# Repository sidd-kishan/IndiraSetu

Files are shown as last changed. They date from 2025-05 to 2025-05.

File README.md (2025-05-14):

# IndraSetu
## pi pico <-> ft232h
#### GPIO2 -> CLKOUT
#### GPIO3 -> RXF#
#### GPIO4 -> TXE#

#### GPIO5 -> OE#
#### GPIO6 -> RD#
#### GPIO7 -> WR#

#### GPIO8 -> BIT0

#### 3v3  + 3.3v -> ili9341 VCC -> LED ( this is for the lcd back light will be only be labled as led ) needs 3v3 volts from both the chips to balance current draw.

## pi pico -> ili9341 

Sending data which is emiting from pc through ft232h into pi pico with the help of PIO state machine

(PC + FT232H) -> Pi Pico

https://ftdichip.com/wp-content/uploads/2023/09/DS_FT232H.pdf page9


https://ftdichip.com/wp-content/uploads/2020/08/TN_167_FIFO_Basics.pdf page15


Refrences:-
[AN130](https://ftdichip.com/wp-content/uploads/2020/08/AN_130_FT2232H_Used_In_FT245-Synchronous-FIFO-Mode.pdf)
[AN135](https://www.ftdichip.com/Documents/AppNotes/AN_135_MPSSE_Basics.pdf)
[AN165](https://www.ftdichip.com/Documents/AppNotes/AN_165_Establishing_Synchronous_245_FIFO_Communications_using_a_Morph-IC-II.pdf)
[AN167](https://ftdichip.com/wp-content/uploads/2020/08/TN_167_FIFO_Basics.pdf)
[AN124](https://www.ftdichip.cn/Support/Documents/AppNotes/oldAN_124_User_Guide_For_FT_PROG.pdf)



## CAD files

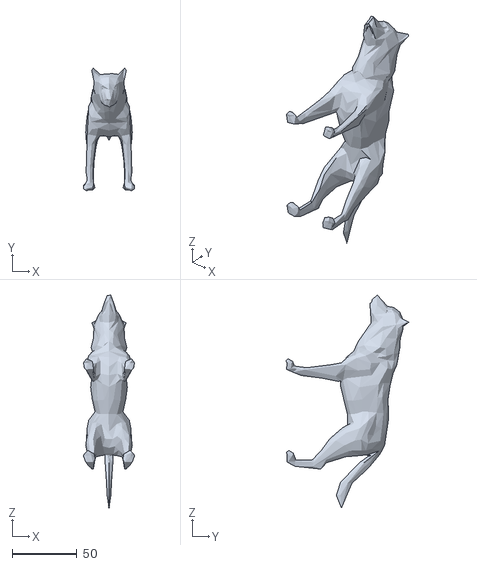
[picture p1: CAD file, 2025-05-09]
WOLF.obj
39.3 x 94.6 x 164.0

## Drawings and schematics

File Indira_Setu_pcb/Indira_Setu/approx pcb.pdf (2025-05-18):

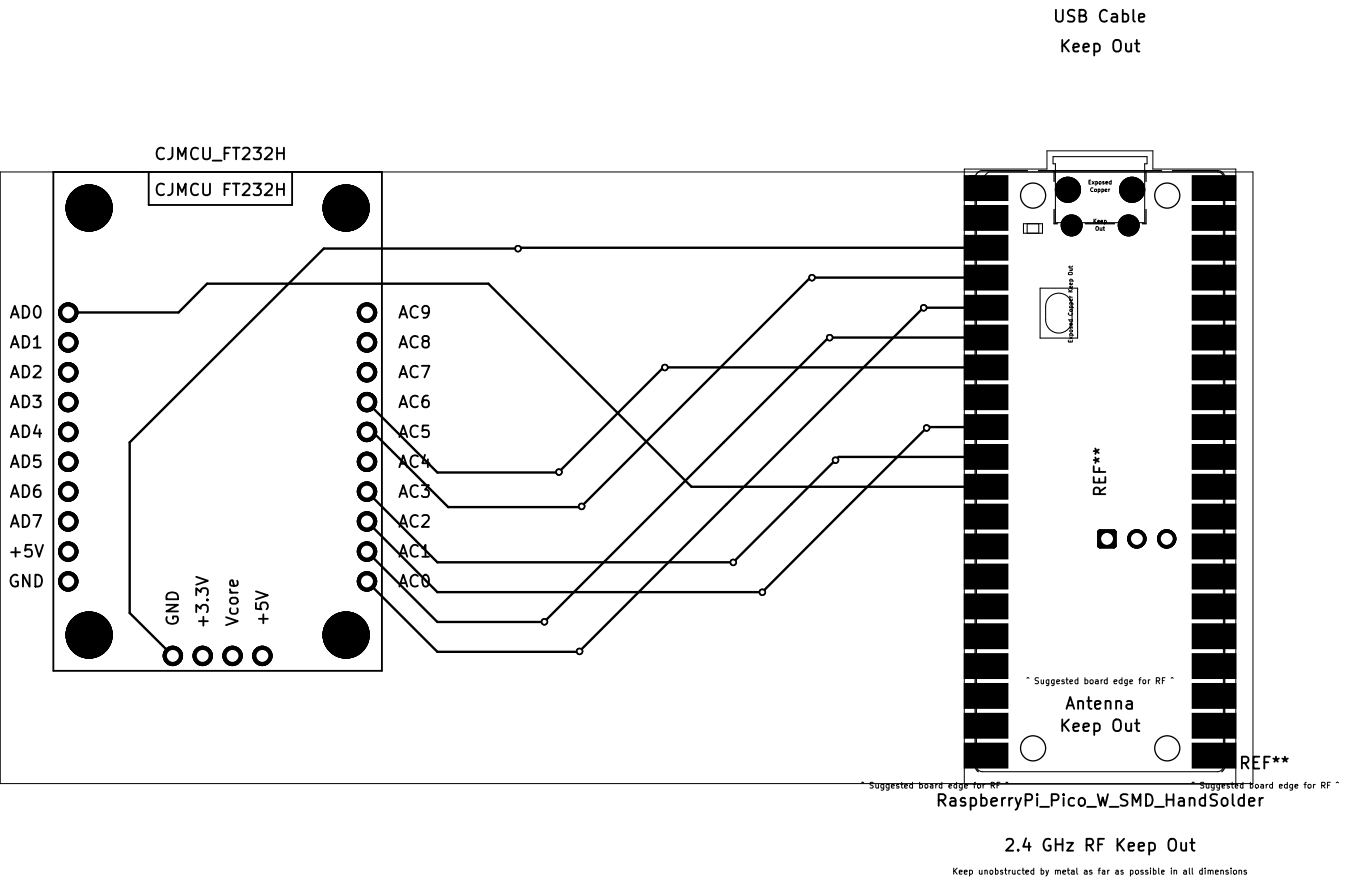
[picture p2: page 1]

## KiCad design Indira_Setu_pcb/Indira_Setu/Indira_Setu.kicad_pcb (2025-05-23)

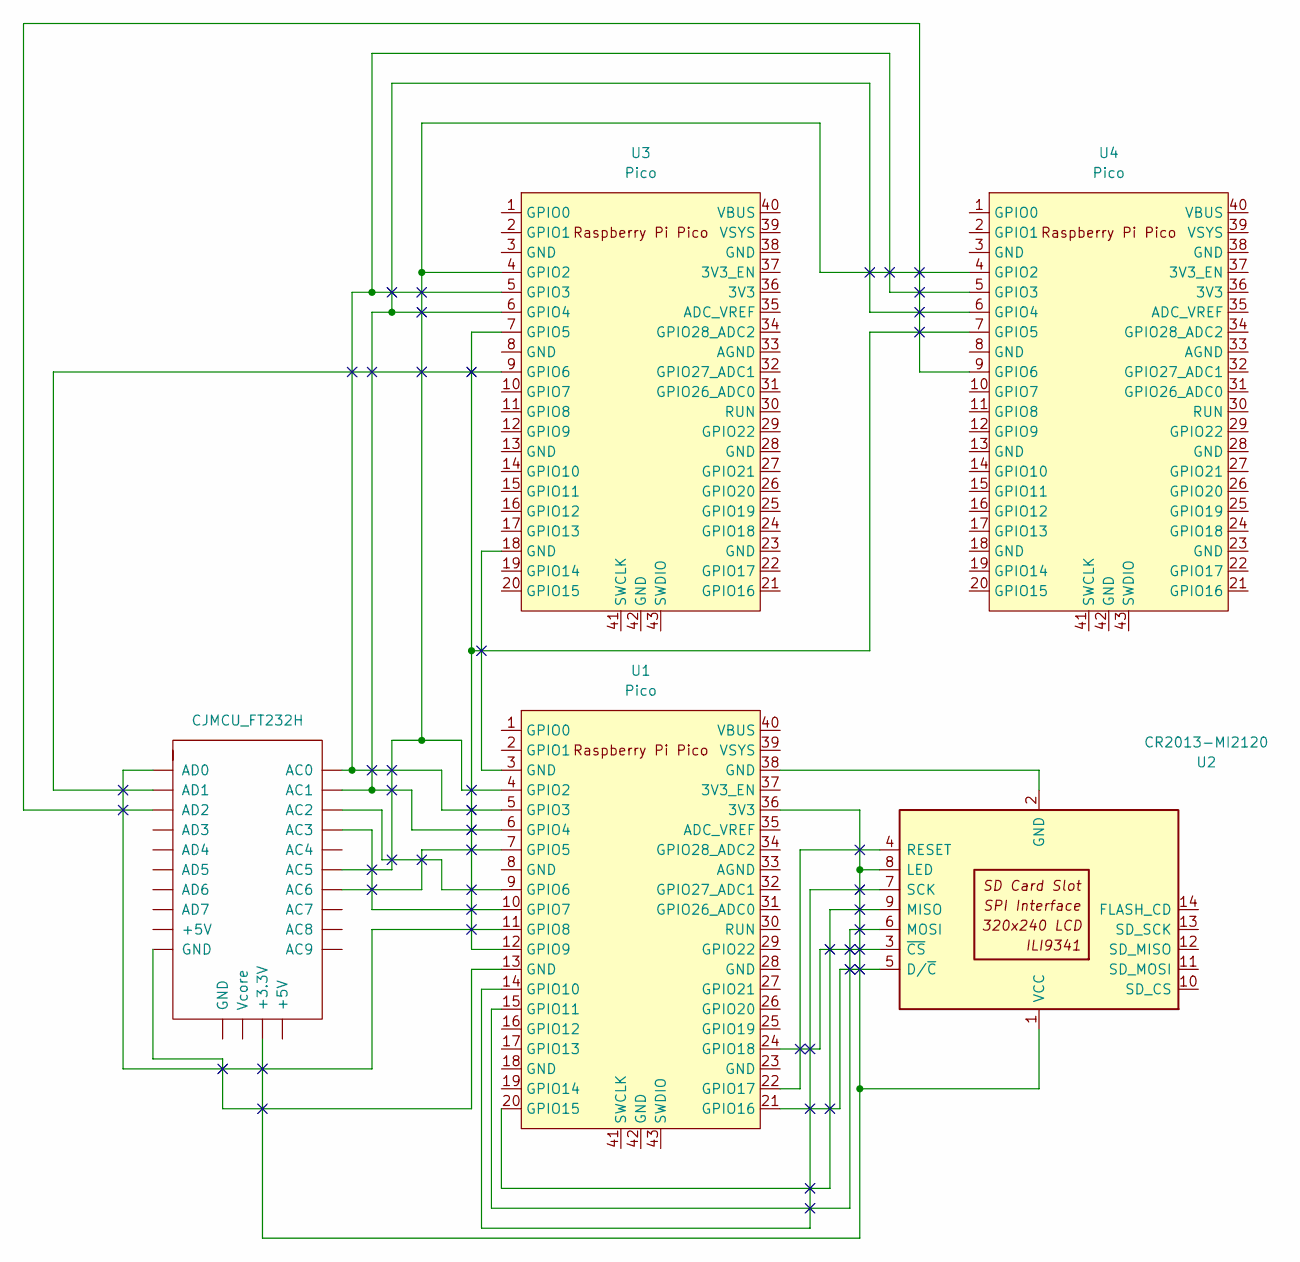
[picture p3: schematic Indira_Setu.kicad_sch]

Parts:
CJMCU_FT1: CJMCU_FT232H
U1, U3, U4: Pico; RPi_Pico_SMD_TH
U2: CR2013-MI2120

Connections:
unnamed: CJMCU_FT1.GND1 (GND), U1.13 (GND)
unnamed: CJMCU_FT1.+3.3V, U1.36 (3V3), U2.1 (VCC), U2.8 (LED)
unnamed: U1.3 (GND), U3.18 (GND)
unnamed: CJMCU_FT1.AC5, U1.4 (GPIO2), U3.4 (GPIO2), U4.4 (GPIO2)
unnamed: CJMCU_FT1.AC0, U1.5 (GPIO3), U3.5 (GPIO3), U4.5 (GPIO3)
unnamed: CJMCU_FT1.AC1, U1.6 (GPIO4), U3.6 (GPIO4), U4.6 (GPIO4)
unnamed: CJMCU_FT1.AC6, U1.7 (GPIO5)
unnamed: CJMCU_FT1.AC2, U1.9 (GPIO6)
unnamed: CJMCU_FT1.AC3, U1.10 (GPIO7)
unnamed: CJMCU_FT1.AD0, U1.11 (GPIO8)
unnamed: U1.12 (GPIO9), U3.7 (GPIO5), U4.7 (GPIO5)
unnamed: U1.14 (GPIO10), U2.7 (SCK)
unnamed: U1.15 (GPIO11), U2.6 (MOSI)
unnamed: U1.20 (GPIO15), U2.9 (MISO)
unnamed: U1.21 (GPIO16), U2.5 (D/~C)
unnamed: U1.22 (GPIO17), U2.4 (RESET)
unnamed: U1.24 (GPIO18), U2.3 (~CS)
unnamed: U1.38 (GND), U2.2 (GND)
unnamed: CJMCU_FT1.AD1, U3.9 (GPIO6)
unnamed: CJMCU_FT1.AD2, U4.9 (GPIO6)

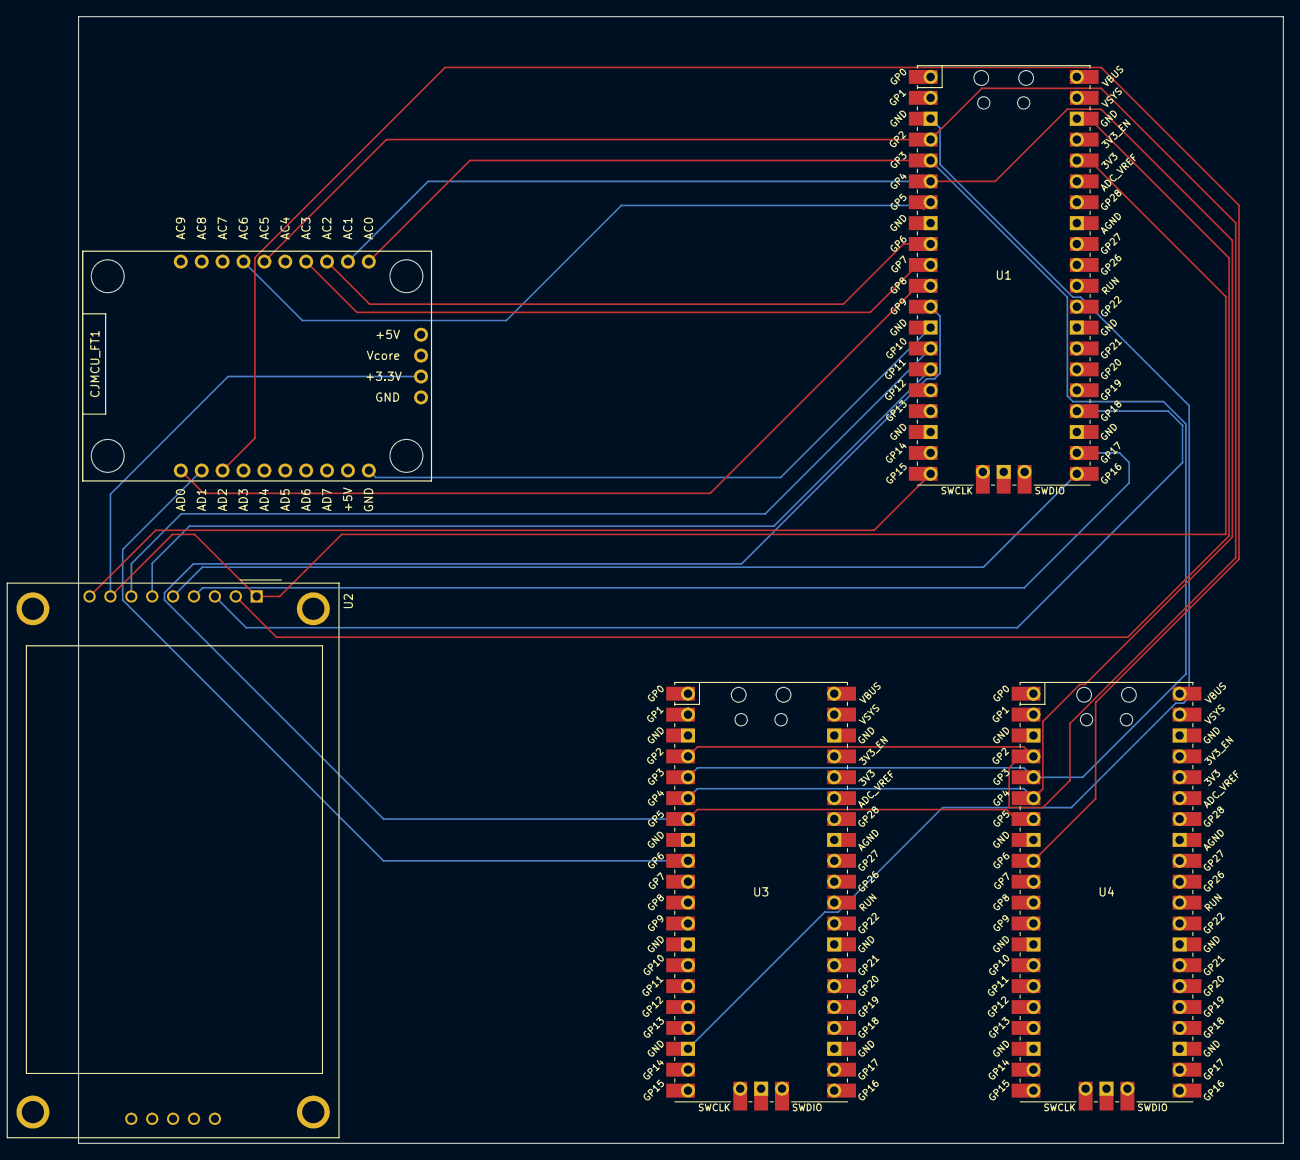
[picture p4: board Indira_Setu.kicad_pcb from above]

Board: 2 copper layers, 146.5 x 137.0 mm, 5 parts (0 on the bottom side), 20 nets.

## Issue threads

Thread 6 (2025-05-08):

Move the pattern matching of 0xA5 to PIO SM

sidd-kishan, 2025-05-08:
if we have pattern matching in the pio SM then we will have better corruption resistance. addition to this if we have a centralised psram to store cordinates it is possible due to the distributed nature of the 8 pi picos we can have a better chance to recover a packet.

psuedo:-

mov(y,0xa5)
wrap()
in_(pins, 1)
jmp("loop", cmp(isr,y))
wrap_target()

sidd-kishan, 2025-05-09:
should look something like the following: -

    jmp pin, pass1 side 0b111 [1]
    jmp loop side 0b111
pass1:
    jmp pin, pass2 side 0b111 [3]
    jmp loop side 0b111
pass2:
    jmp pin, pass3 side 0b111 [1]
    jmp loop side 0b111
pass3:
    jmp pin, start_wrap side 0b111
    jmp loop side 0b111
start_wrap:

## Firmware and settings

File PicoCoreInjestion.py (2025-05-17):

from machine import Pin, SPI  # type: ignore
from random import random, seed, randint
from ili9341 import Display, color565
from utime import sleep_us, ticks_cpu, ticks_us, ticks_diff  # type: ignore
import _thread
import time
import rp2
import framebuf
import gc
import os
import math
import heapq
import uarray as array

heap = []

heapq.heapify(heap)

pin2=Pin(2,Pin.IN)   #clkout -> AC5
pin3=Pin(3,Pin.IN)   #RXF#   -> AC0
pin4=Pin(4,Pin.IN)   #TXE#   -> ?

pin5=Pin(5,Pin.OUT,Pin.PULL_UP) # OE# -> AC6
pin6=Pin(6,Pin.OUT,Pin.PULL_UP) # RD# -> AC2
pin7=Pin(7,Pin.OUT,Pin.PULL_UP) # WR# -> AC3

pin5.value(1)
pin6.value(1)
pin7.value(1)

pin8=Pin(8,Pin.IN,Pin.PULL_UP)  # 1 bit -> AD0

hit = 0
miss = 0
pkt_tot_len = 0



@rp2.asm_pio(set_init=[rp2.PIO.OUT_LOW],sideset_init=(rp2.PIO.OUT_HIGH,rp2.PIO.OUT_HIGH,rp2.PIO.OUT_HIGH),autopush=True, push_thresh=32,in_shiftdir=rp2.PIO.SHIFT_LEFT)
def wait_pin_low():
	#wrap_target()
	wait(0, gpio, 3).side(7)
	irq(block, rel(0)).side(7)
	pull(block).side(7)
	mov(x,osr).side(7)
	mov(isr,null).side(7)
	set(pindirs,0).side(7)
	wait(1, gpio, 2).side(7)
	wait(0, gpio, 2).side(6)
	#in_(isr,32).side(6)
	label("loop")
	in_(pins,1).side(4)
	jmp(x_dec,"loop").side(4)


def handler(sm):
	# Print a (wrapping) timestamp, and the state machine object.
	global recv_start
	#print(time.ticks_ms(), sm)
	#sm_got = bin(sm.get())[2:]
	#print(sm_got)
	sm.put(256)
	recv_start=1



# Instantiate StateMachine(1) with wait_pin_low program on Pin(17).
sm1 = rp2.StateMachine(0, wait_pin_low,freq=120_000_000, sideset_base=pin5, in_base=pin8)
sm1.irq(handler)

def crc8(data):
    crc = 0x00
    for byte in data:
        crc ^= byte
        for _ in range(8):
            if crc & 0x80:
                crc = (crc << 1) ^ 0x07
            else:
                crc <<= 1
            crc &= 0xFF  # Keep it 8-bit
    return crc


# Now, when Pin(16) or Pin(17) is pulled low a message will be printed to the REPL.
def main():
    global hit
    global miss
    global pkt_tot_len
    recv_start = 1
    qsz = 0
    while True:
        bin_str = ""
        #while pin3.value() == 0:
        sm1.active(1)
        #time.sleep(0.0000001)
        while sm1.rx_fifo():#qsz < 8:
            sm_got = bin(sm1.get())[2:]
            if len(sm_got) > 2:
                bin_str = bin_str + sm_got
                #pkt_mark_s = bin_str.find("01011010")
                if len(bin_str) >255:
                    #print(bin_str[:128])
                    pkt_mark = bin_str.find("10100101")
                    if pkt_mark > -1 and pkt_mark < 10:
                        bin_str = bin_str[pkt_mark+8:]
                        str_got = ""
                        crc_input = bytearray()
                        for i in range(0, len(bin_str[:256]), 8):
                            byte = bin_str[i:i+8]
                            str_got += chr(int(byte, 2))
                            crc_input.append(int(byte, 2))
                        if crc8(crc_input[:6]) == crc_input[12] and crc8(crc_input[6:12]) == crc_input[13]:
                            hit+=1
                            heapq.heappush(heap, [crc_input[0],crc_input[1],crc_input[2],crc_input[3],crc_input[4],crc_input[5],crc_input[6],crc_input[7],crc_input[8],crc_input[9],crc_input[10],crc_input[11],crc_input[12],crc_input[13],crc_input[14]])                            
                        elif crc8(crc_input[:6]) == crc_input[12]:
                            hit+=1
                            heapq.heappush(heap, [crc_input[0],crc_input[1],crc_input[2],crc_input[3],crc_input[4],crc_input[5],0,0,0,0,0,0,crc_input[12],crc_input[13],crc_input[14]])
                        elif crc8(crc_input[6:12]) == crc_input[13]:
                            hit+=1
                            heapq.heappush(heap, [0,0,0,0,0,0,crc_input[6],crc_input[7],crc_input[8],crc_input[9],crc_input[10],crc_input[11],crc_input[12],crc_input[13],crc_input[14]])
                        #elif crc8(crc_input[:12]) == crc_input[14]:
                        #    hit+=1
                        #    heapq.heappush(heap, [crc_input[0],crc_input[1],crc_input[2],crc_input[3],crc_input[4],crc_input[5],crc_input[6],crc_input[7],crc_input[8],crc_input[9],crc_input[10],crc_input[11],crc_input[12],crc_input[13],crc_input[14]])
                        else:
                            miss +=1
                            #print("salvaged trig2")
                            #msg+= str("salvage trig2: "+str(trig2%255)+" sum sum: "+str(crc_input[13]))
                        #if msg !="":
                        #    print(msg)
                        #print("crc8 invalid:"+ str(crc_input[0])+" "+ str(crc_input[1])+" "+ str(crc_input[2])+" " + str(crc_input[3])+" "+ str(crc_input[4])+" "+ str(crc_input[5])+" " + str(crc_input[6])+" "+ str(crc_input[7])+" "+ str(crc_input[8])+" " + str(crc_input[9])+" "+ str(crc_input[10])+" "+ str(crc_input[11])+" " + str(crc_input[12])+" "+ str(crc_input[13]))
                #if len(bin_str) >127 and pkt_mark_s > -1 and pkt_mark_s < 10:
                #    bin_str = bin_str[pkt_mark_s+8:]
                #    str_got = ""
                #    for i in range(0, len(bin_str[:128]), 8):
                #        byte = bin_str[i:i+8]
                #        str_got += chr(int(byte, 2))
                #    print("s: "+str_got)
        sm1.active(0)
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

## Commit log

2025-01-21 Create FTDI-Sender.cpp
    It arranges "hello world" in a buffer of 1024 bytes and sends 1st 255 bytes over and over again as 255 = 32 bytes which is the size of the rx fifo in pi pico pio side not any other reason.
    h - 01101000
    e - 01100101
    l - 01101100
    l - 01101100
    o - 01101111
    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
2025-04-19 Update PicoCoreInjestion.py
    1 bit error correction added
    [PicoCoreInjestion.py]
2025-04-21 Update PicoCoreInjestion.py
    Interrupt driven code pattern for efficient data acquisition
2025-04-21 Update PicoCoreInjestion.py
    just juggling for stability
    [PicoCoreInjestion.py]
2025-04-22 Update PicoCoreInjestion.py
    Trying over sampling
    >>> %Run -c $EDITOR_CONTENT
    MPY: soft reboot
    11100010100100010001100101001011
    11001100110111100000000011110
    11011011110011001001100110011001
    10110100100010001100101101101
    11001100110111110010000011110
    11111011111011101001100110001001
    10101100100010000100101101101
    11001100010111110010000011110
    11111111111111111111111111111111
    11111111111111111111111111111111
    11111111111111111111111111111111
    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
    [PicoCoreInjestion.py]
2025-04-22 Update PicoCoreInjestion.py
    01001000 : H
    01100101 : e
    01101111 : o
    01100011 : c
    01111001 : y
    00000011 :
    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
2025-04-23 Update PicoCoreInjestion.py
    Debugging code added I think the wiring is short
    ------------------
    Pin 3 went LOW!
    -1
    ***********************
    -1
    ***********************
    -1
    ***********************
    -1
    ***********************
    -1
    ***********************
    ------------------
    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
    [PicoCoreInjestion.py]
2025-04-24 Update PicoCoreInjestion.py
    we need to make it 32 to not loose on 8 bits across fifo
    [PicoCoreInjestion.py]
2025-04-26 Update PicoCoreInjestion.py
    1110010101010011000011010000110110001011100011011100010000001100111011011100111001001011100011001011010101001001000011001010011011000110110001101111001000000111111011011110111001001101100011010010111010010010000110010100111100011011000110111100100000011
    11100101010000010000110000101101100011011000110111100100000011101110110111101110010011011000110010010101010010010000110010100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
    [PicoCoreInjestion.py]
2025-04-26 Update PicoCoreInjestion.py
    pio stability added
    [PicoCoreInjestion.py]
2025-05-08 Update PicoCoreInjestion.py
    Frame Buffering added
2025-05-10 Update FTDI-Sender.cpp
    triag print
2025-05-10 Update PicoCoreInjestion.py
    hex encoded print
2025-05-13 Update PicoCoreInjestion.py
    Slow Read achieved, lots of noise following is the packet summary:-
    24.47%
    hit: 1 bytes on 8 channels recv: 14 miss: 7 and crc8 verified:150 83 146 87 146 90 79 159 76 168 78 162 79 243
    14.00651
    hit: 2 bytes on 8 channels recv: 28 miss: 24 and crc8 verified:131 94 134 100 135 114 227 172 78 174 83 174 82 47
    14.07472
    hit: 3 bytes on 8 channels recv: 42 miss: 40 and crc8 verified:123 93 129 84 128 87 171 196 41 196 41 195 44 226
    hit: 4 bytes on 8 channels recv: 56 miss: 53 and crc8 verified:114 114 119 118 116 120 190 194 53 200 51 195 44 200
    14.0447
    hit: 5 bytes on 8 channels recv: 70 miss: 54 and crc8 verified:151 51 147 47 155 46 230 164 67 162 55 15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
    [PicoCoreInjestion.py]
2025-05-13 Add files via upload
    wolf.obj to csv
    [data.csv]
2025-05-14 Update PicoCoreInjestion.py
    rendering to SPI LCD added
2025-05-16 Update PicoCoreInjestion.py
    need to add feedback for repeating filtered triangle
2025-05-18 PCB file added
